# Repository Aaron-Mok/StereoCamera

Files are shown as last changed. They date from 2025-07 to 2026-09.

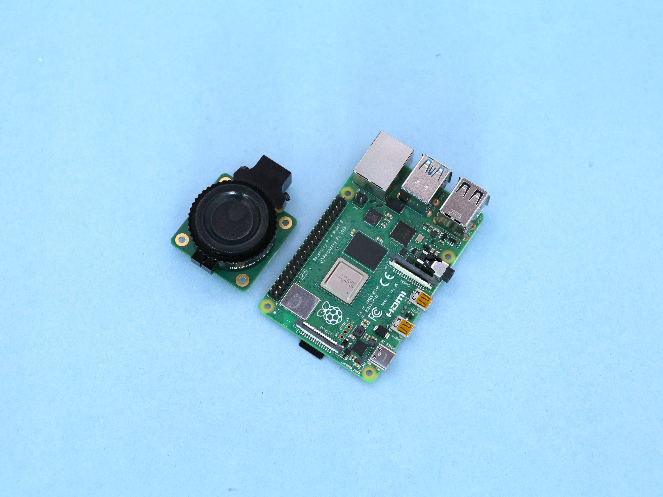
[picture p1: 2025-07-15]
CAD/Raspberry Pi HQ Camera Case - 4420496/images/parts-crop.jpg

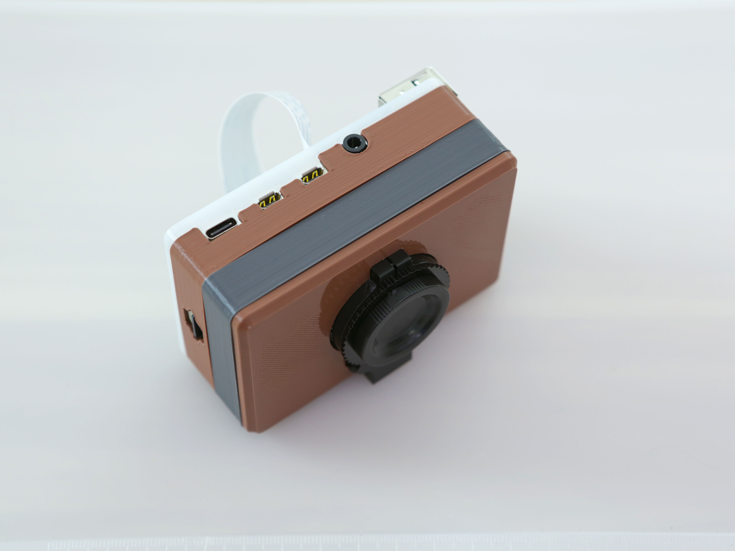
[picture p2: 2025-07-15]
CAD/Raspberry Pi HQ Camera Case - 4420496/images/final-build-top.jpg

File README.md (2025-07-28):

# Stereo Camera System

**Author:** Aaron Mok  
**Keywords:** Optics, Stereo Vision, Raspberry Pi HQ Camera, Depth Estimation, ISP Pipeline, Distortion Correction, Python, OpenCV, 3D Printing, CADing

## Overview

This project aims to build a complete **stereo camera system from scratch** using two Raspberry Pi HQ cameras. The system captures synchronized raw Bayer images, processes them through a custom image signal processing (ISP) pipeline, and performs stereo calibration and depth estimation. It also includes the design and fabrication of a **custom 3D-printed mount** to ensure precise camera alignment.

This project showcases the complete stereo vision pipeline, from lens and sensor selection to camera alignment and image processing, with the goal of achieving accurate and reliable depth reconstruction.

## Features

- **Raw Image Capture** from dual Raspberry Pi HQ cameras  
- **Custom ISP Pipeline** including:
  - Stride/padding correction
  - Black level subtraction
  - Distortion correction
  - Lens shading correction
  - Demosaicing
  - White balance
  - Color calibration
  - Gamma correction
- **Stereo Calibration & Rectification**
- **Disparity & Depth Map Generation**
- **Custom 3D-Printed Mount** for accurate and stable stereo alignment
- Real-time visualization and debugging tools
- Modular and extensible Python codebase

## Current Progress
**Status:** Ongoing Project  
- [x] Image signal processing for raw capture
  - [x] Stride/padding correction
  - [x] Black level subtraction
  - [ ] Distortion correction
  - [x] Lens shading correction
  - [x] Demosaicing
  - [x] White balance
  - [x] Color calibration
  - [x] Gamma correction
- [ ] 3D-printed mount design and testing
- [ ] Initial stereo calibration
- [ ] Real-time disparity map viewer

## Demo
Coming soon: live video walkthrough, depth map overlay, and stereo reconstruction results.

## About Me
I am an Imaging System Architect at KLA, where I lead the development of advanced optical and imaging subsystems for high-precision inspection tools. I hold a PhD in Biomedical Engineering from Cornell University, where my research focused on developing next-generation optical imaging systems for deep-tissue brain imaging.

See my work and blog at [https://aaron-mok.github.io/](https://aaron-mok.github.io/).

## License
This project is licensed under the **GNU General Public License v3.0**.

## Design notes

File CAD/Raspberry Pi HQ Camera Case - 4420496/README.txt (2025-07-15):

Raspberry Pi HQ Camera Case by adafruit on Thingiverse: https://www.thingiverse.com/thing:4420496

Summary:
In this project we’re making a case for the Raspberry Pi HQ Camera. This 3D printed an enclosure that houses the Pi 4 and the HQ Camera module. It’s compatible with any C or CS-mount lenses so we can use a wide variety of interchangeable lenses.Learn Guidehttps://learn.adafruit.com/raspberry-pi-hq-camera-case/YouTubehttps://youtu.be/g107_ErFv9kFusion 360 Share Linkhttps://a360.co/36TT8MJ3D Model – Raspberry Pi 4https://grabcad.com/library/raspberry-pi-4-model-b-13D Model – Pi HQ Camerahttps://grabcad.com/library/raspberry-pi-hq-camera-2Raspberry Pi 4https://www.adafruit.com/product/4296Raspberry Pi HQ Camerahttps://www.adafruit.com/product/45615.1 3A Power Supplyhttps://www.adafruit.com/product/4298M2.5 black nylon hardwarehttps://www.adafruit.com/product/329935mm 1.6f C-mount lenshttps://www.amazon.com/gp/product/B0773K3MXD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 HDMI cablehttps://www.adafruit.com/product/1322

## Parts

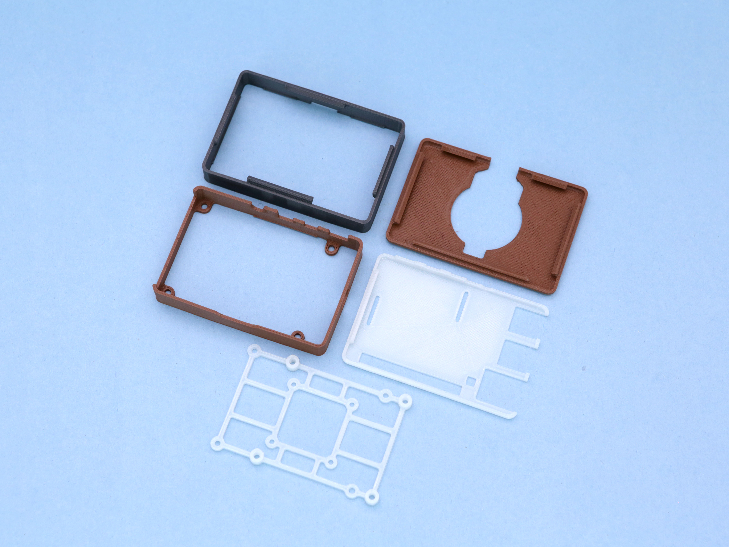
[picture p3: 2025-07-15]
CAD/Raspberry Pi HQ Camera Case - 4420496/images/3d-parts-crop.jpg

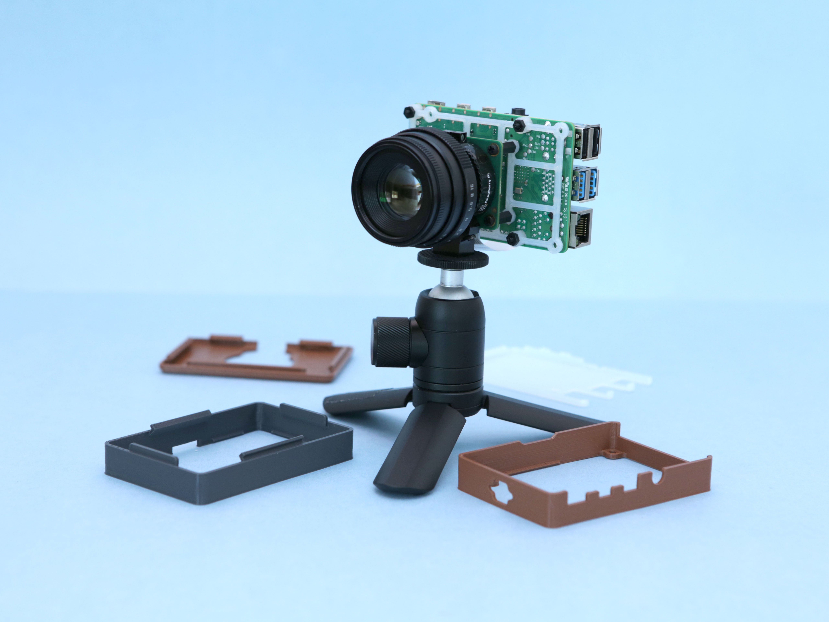
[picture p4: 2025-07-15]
CAD/Raspberry Pi HQ Camera Case - 4420496/images/pcb-mount-parts.jpg

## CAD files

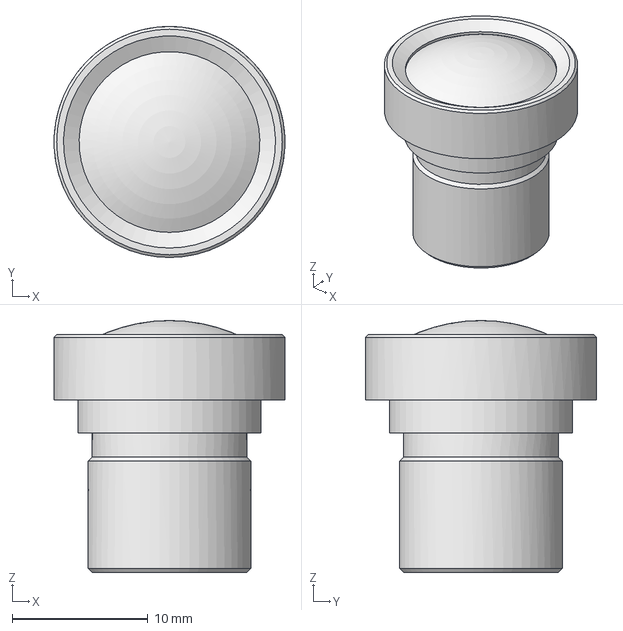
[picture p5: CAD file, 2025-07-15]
CAD/CIL034-F2.7-M12A660 v3/CIL034-F2.7-M12A660 v3.stp
17.0 x 17.0 x 18.5 mm

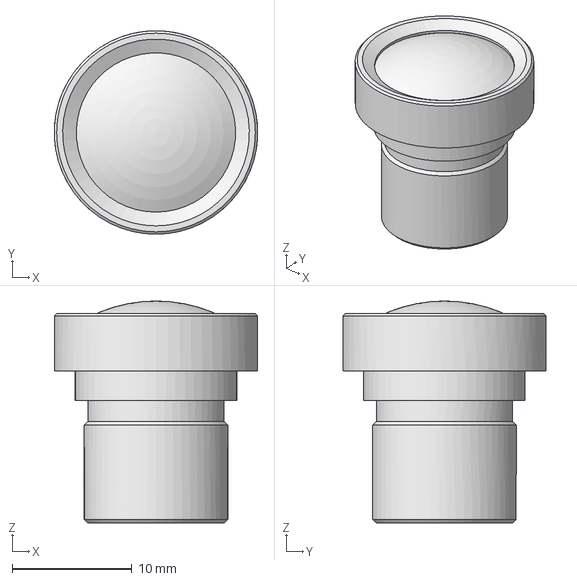
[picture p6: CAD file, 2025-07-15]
CAD/CIL034-F2.7-M12ANIR v3/CIL034-F2.7-M12ANIR v3.stp
17.0 x 17.0 x 18.5 mm

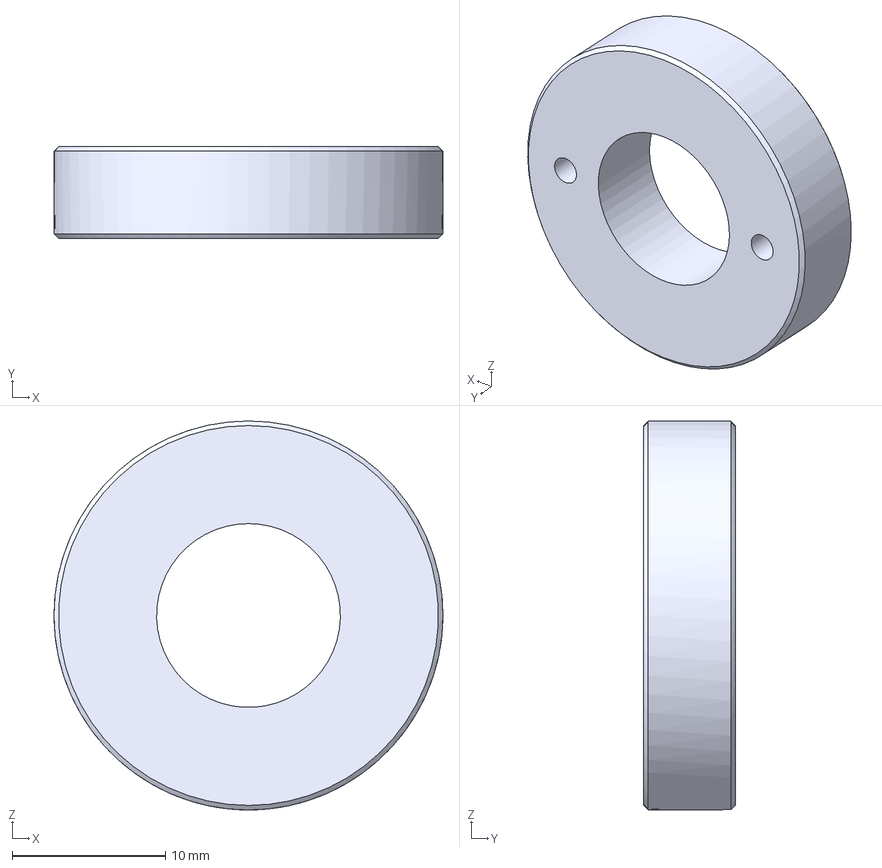
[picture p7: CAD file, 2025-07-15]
CAD/CLA-M12-C-Adapter.stp
25.4 x 6.00 x 25.4 mm

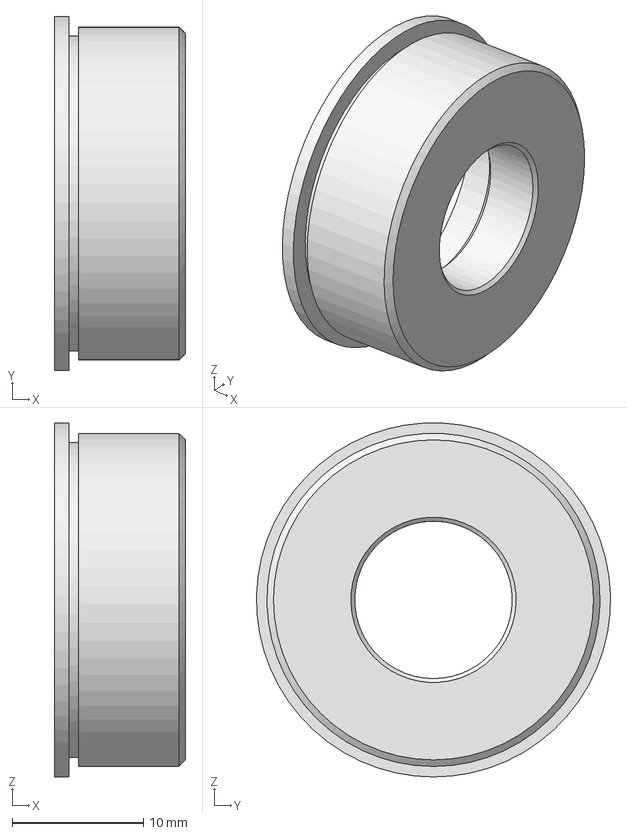
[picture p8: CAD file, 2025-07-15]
CAD/CLA125-CCS/CLA125-CCS.stp
10.00 x 27.0 x 27.0 mm

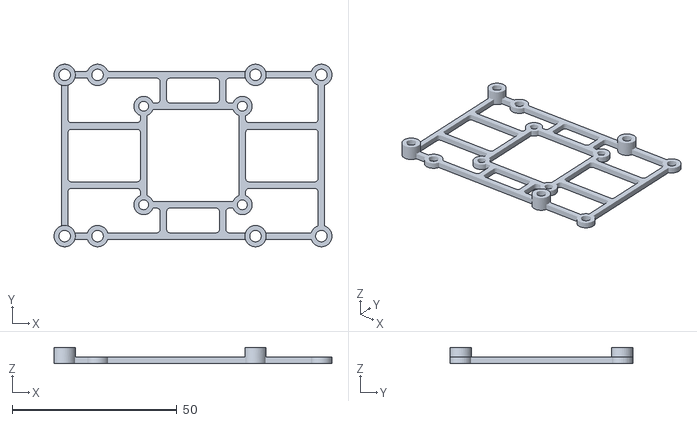
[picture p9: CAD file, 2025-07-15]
CAD/Raspberry Pi HQ Camera Case - 4420496/files/pcb-mount.stl
84.5 x 55.5 x 5.00

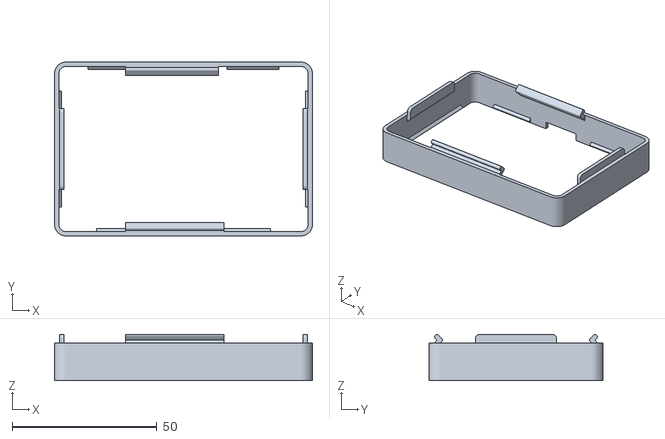
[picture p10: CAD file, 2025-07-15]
CAD/Raspberry Pi HQ Camera Case - 4420496/files/front-frame.stl
89.0 x 60.0 x 16.0

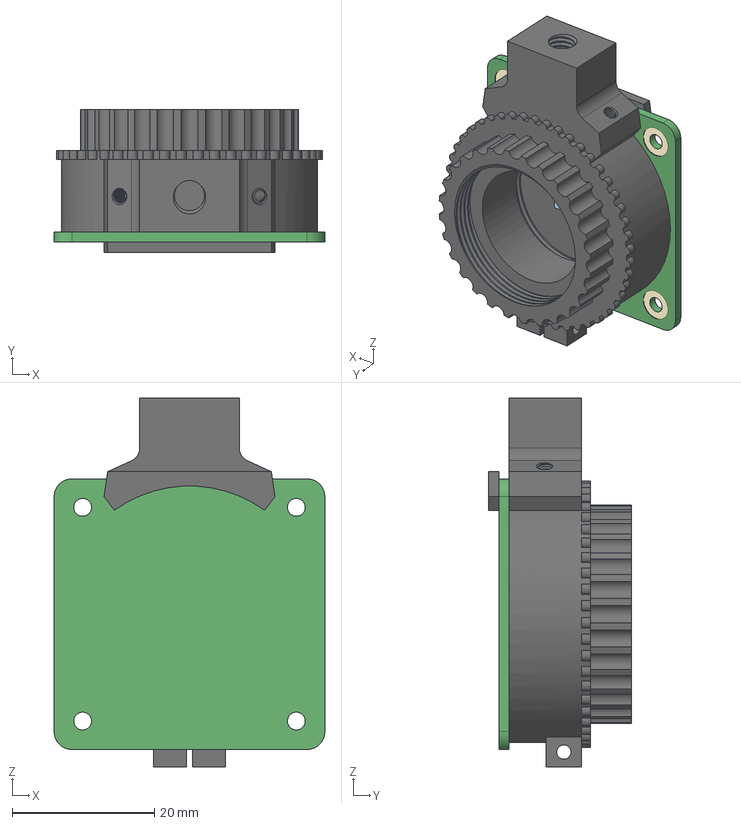
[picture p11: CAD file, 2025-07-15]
CAD/Raspberry Pi HQ Camera.step
38.0 x 20.1 x 51.8 mm

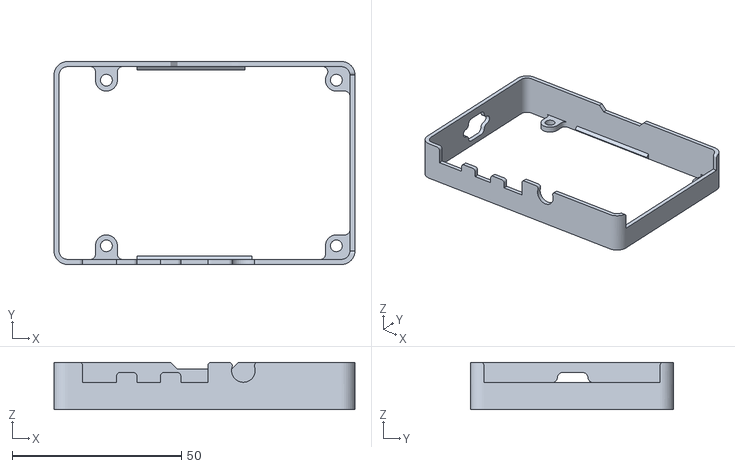
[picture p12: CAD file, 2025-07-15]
CAD/Raspberry Pi HQ Camera Case - 4420496/files/back-frame.stl
89.0 x 60.0 x 14.0

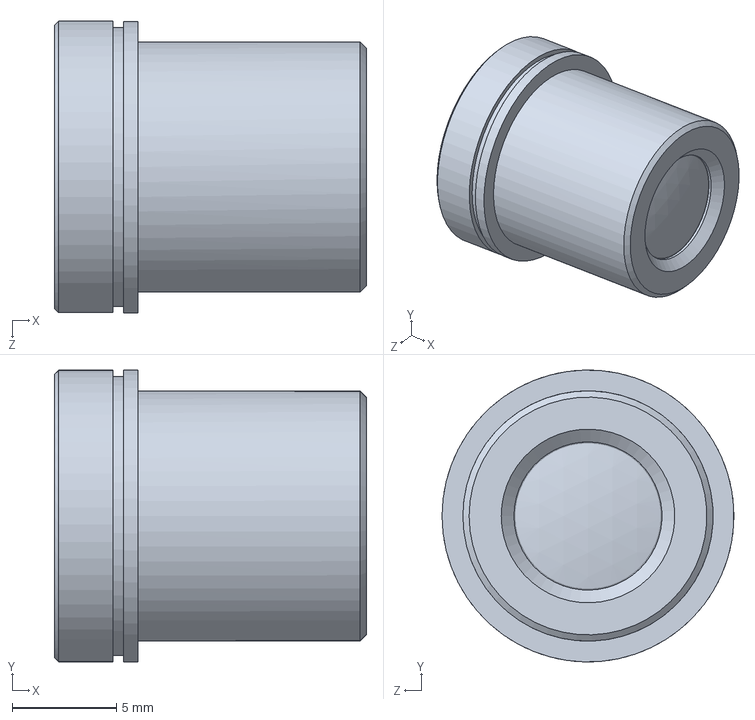
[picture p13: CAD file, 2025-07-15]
CAD/step_69255.step
15.0 x 14.0 x 14.0 mm

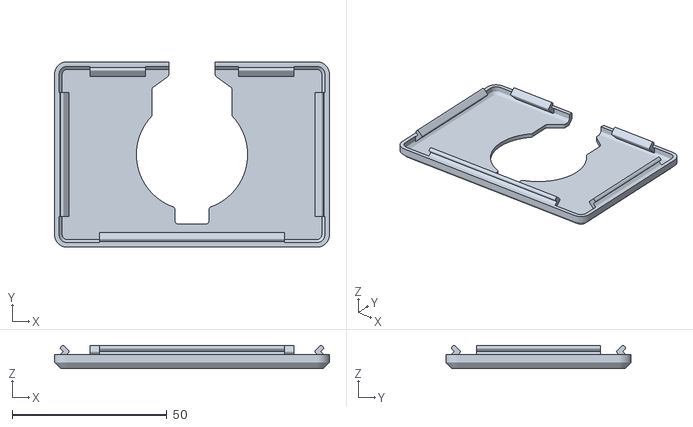
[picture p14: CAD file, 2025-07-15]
CAD/Raspberry Pi HQ Camera Case - 4420496/files/front-cover.stl
89.0 x 60.0 x 7.49

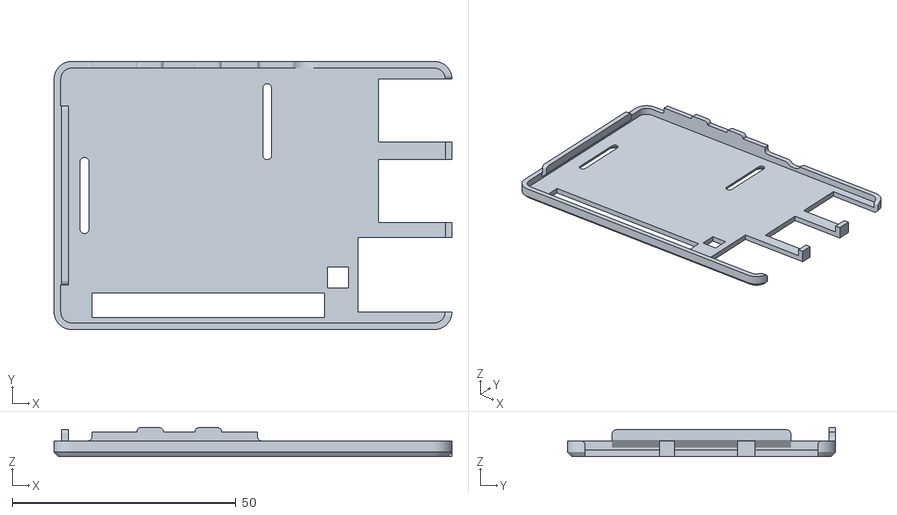
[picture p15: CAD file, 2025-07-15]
CAD/Raspberry Pi HQ Camera Case - 4420496/files/back-cover.stl
89.0 x 60.0 x 6.50

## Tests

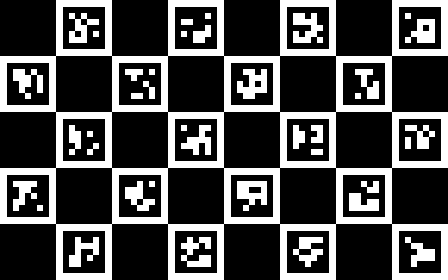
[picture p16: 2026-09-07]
Calibration_output/charuco_8x5_100mm_preview.png

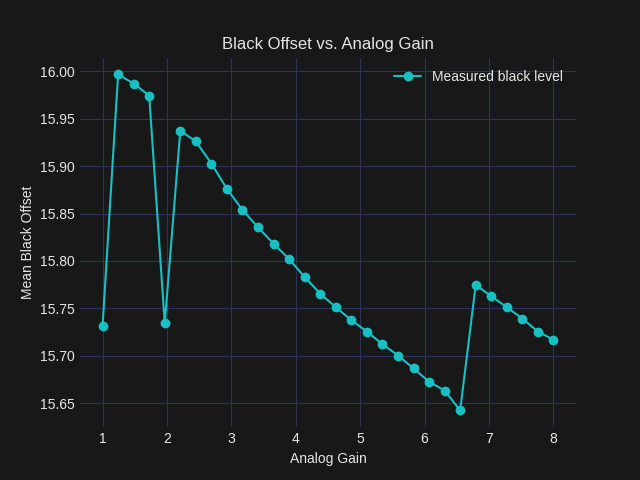
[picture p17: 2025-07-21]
Calibration_output/black_offset.png

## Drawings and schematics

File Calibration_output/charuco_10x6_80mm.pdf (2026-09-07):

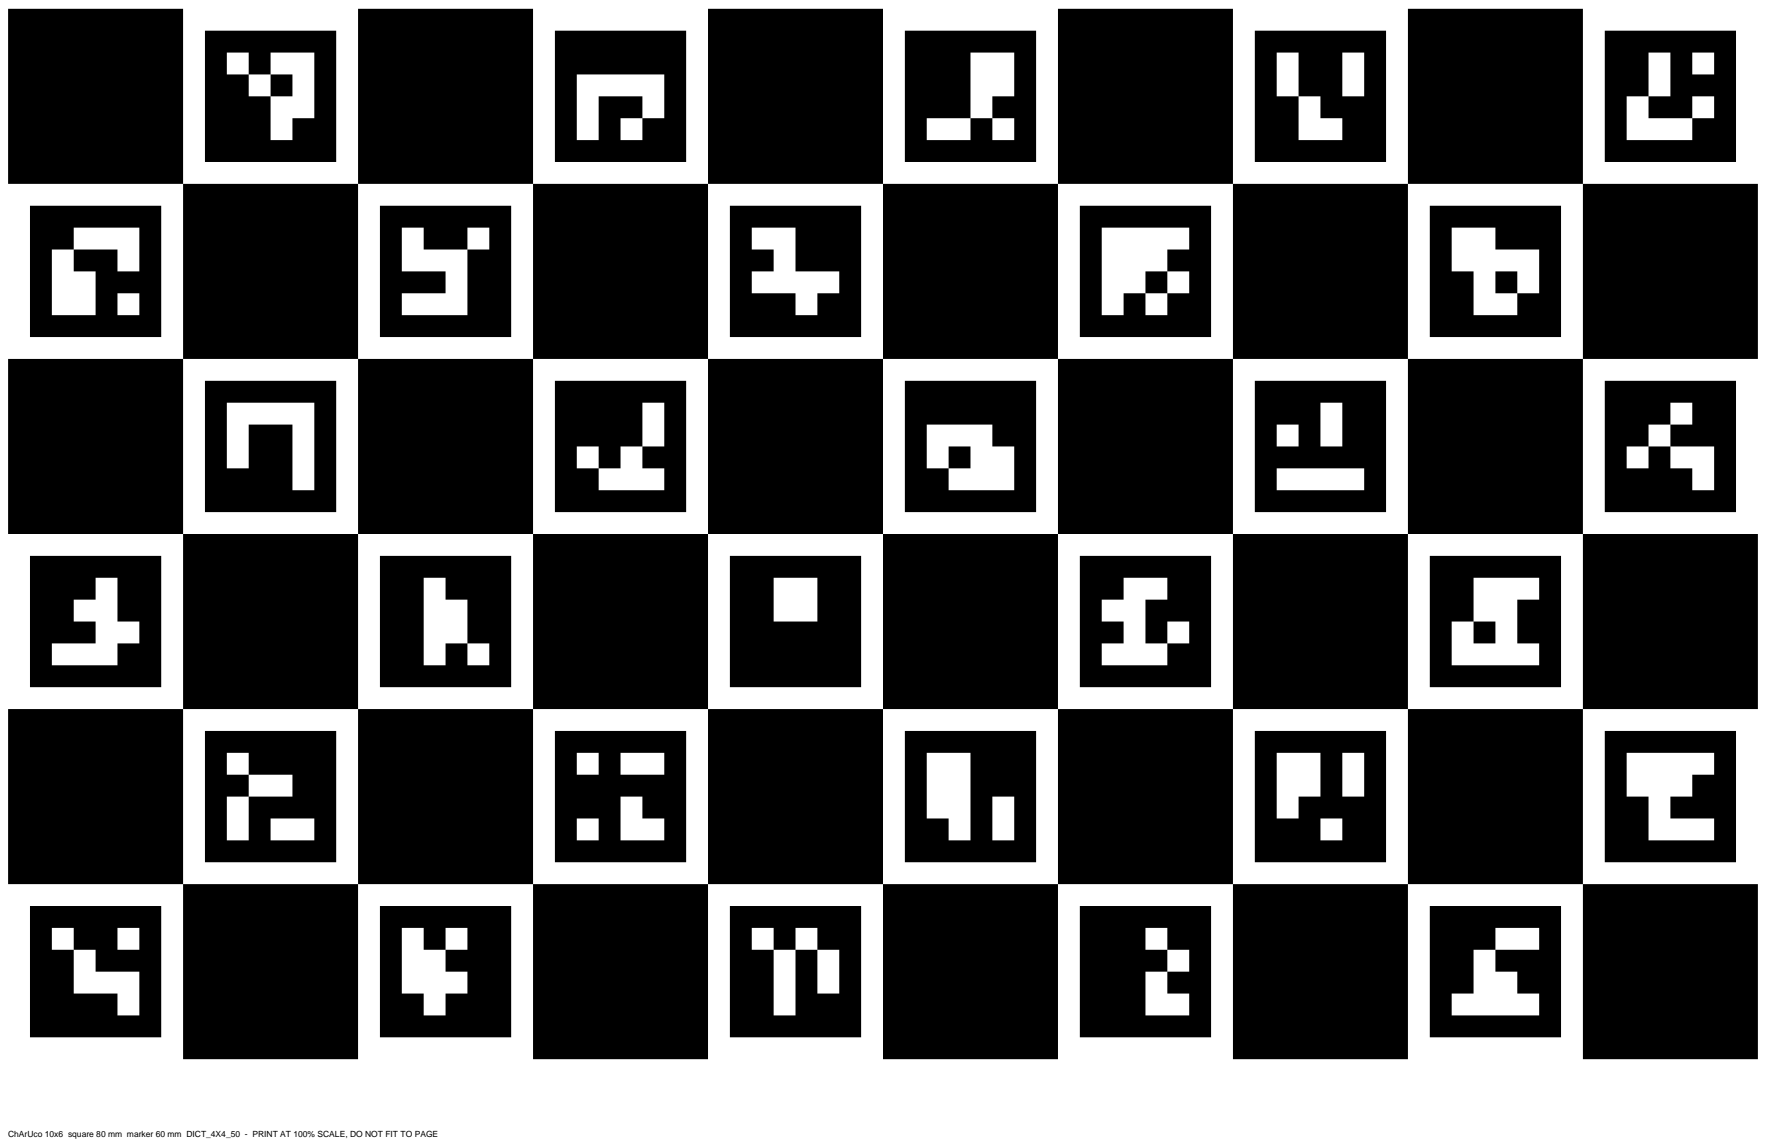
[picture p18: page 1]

ChArUco 10x6 square 80 mm marker 60 mm DICT_4X4_50 - PRINT AT 100% SCALE, DO NOT FIT TO PAGE

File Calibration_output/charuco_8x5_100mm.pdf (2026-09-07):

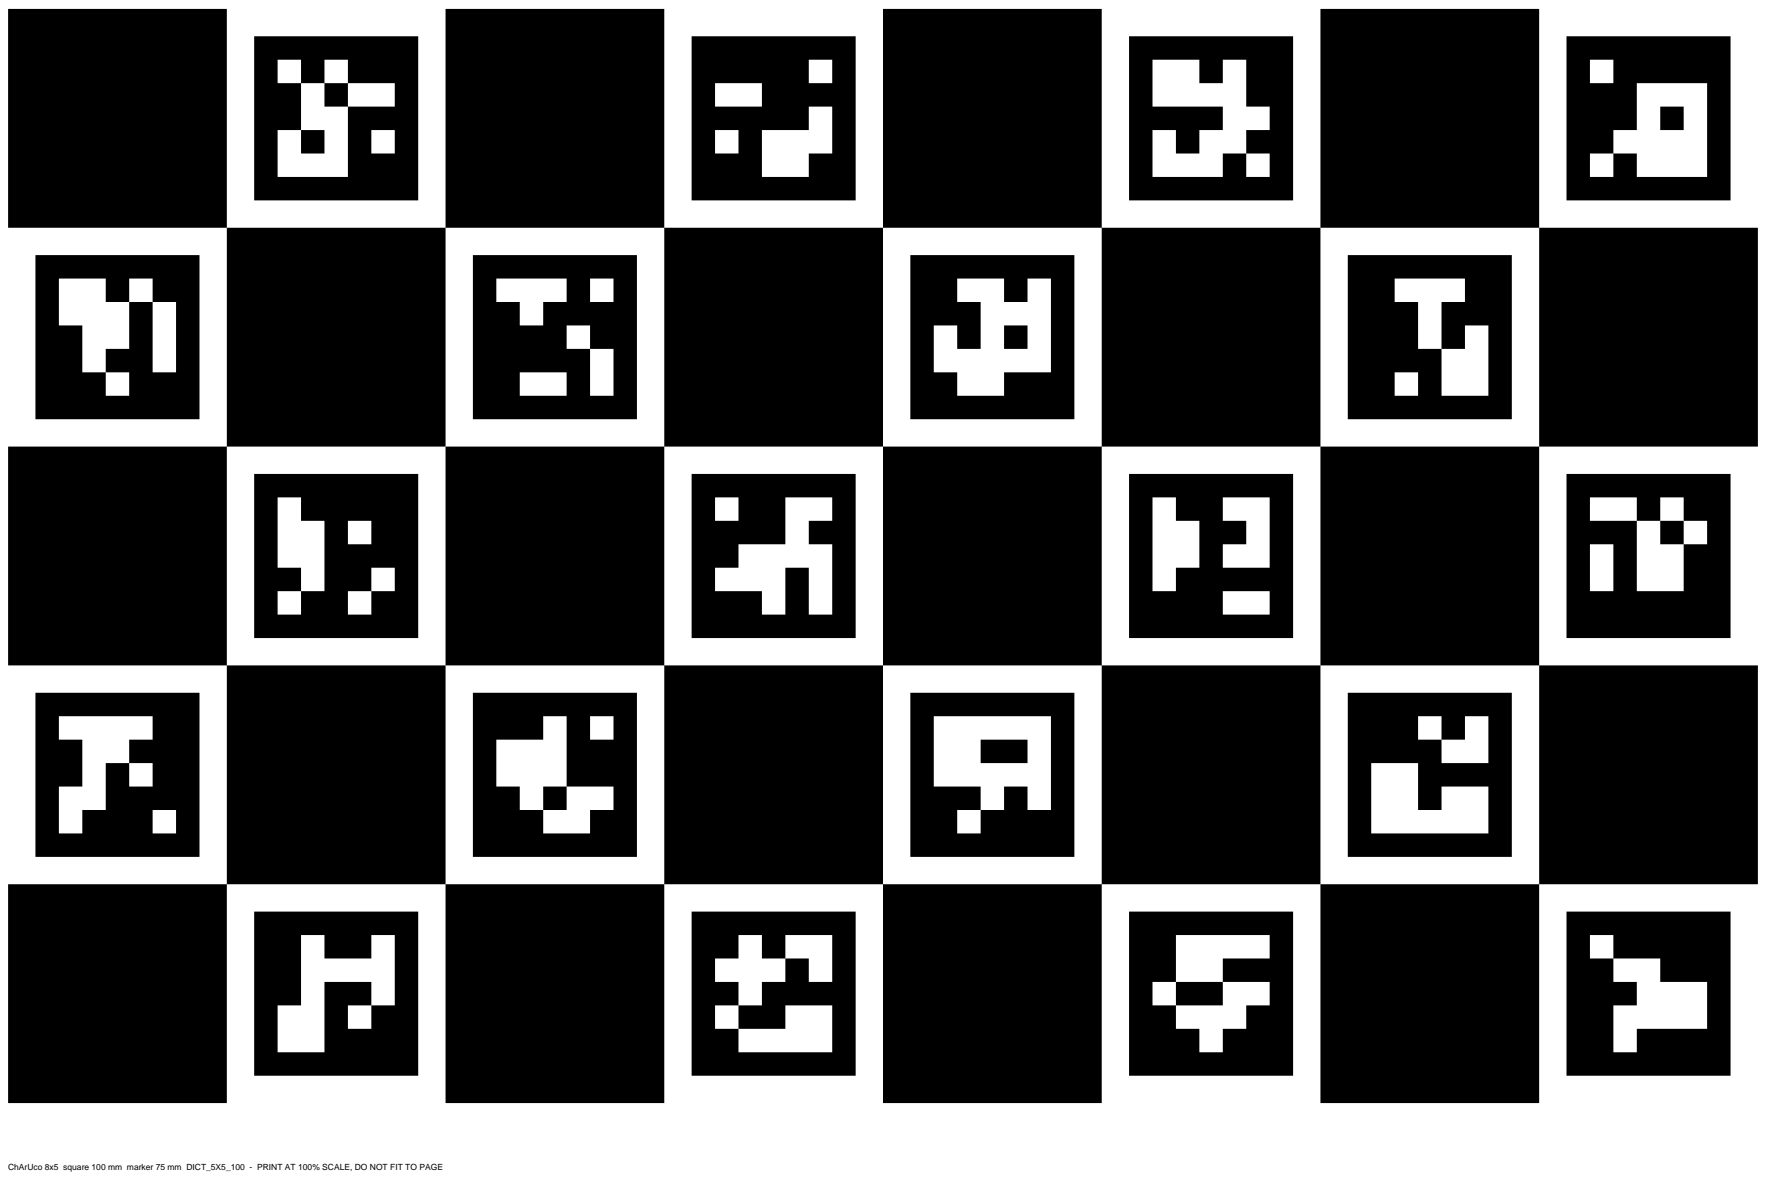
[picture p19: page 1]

ChArUco 8x5 square 100 mm marker 75 mm DICT_5X5_100 - PRINT AT 100% SCALE, DO NOT FIT TO PAGE

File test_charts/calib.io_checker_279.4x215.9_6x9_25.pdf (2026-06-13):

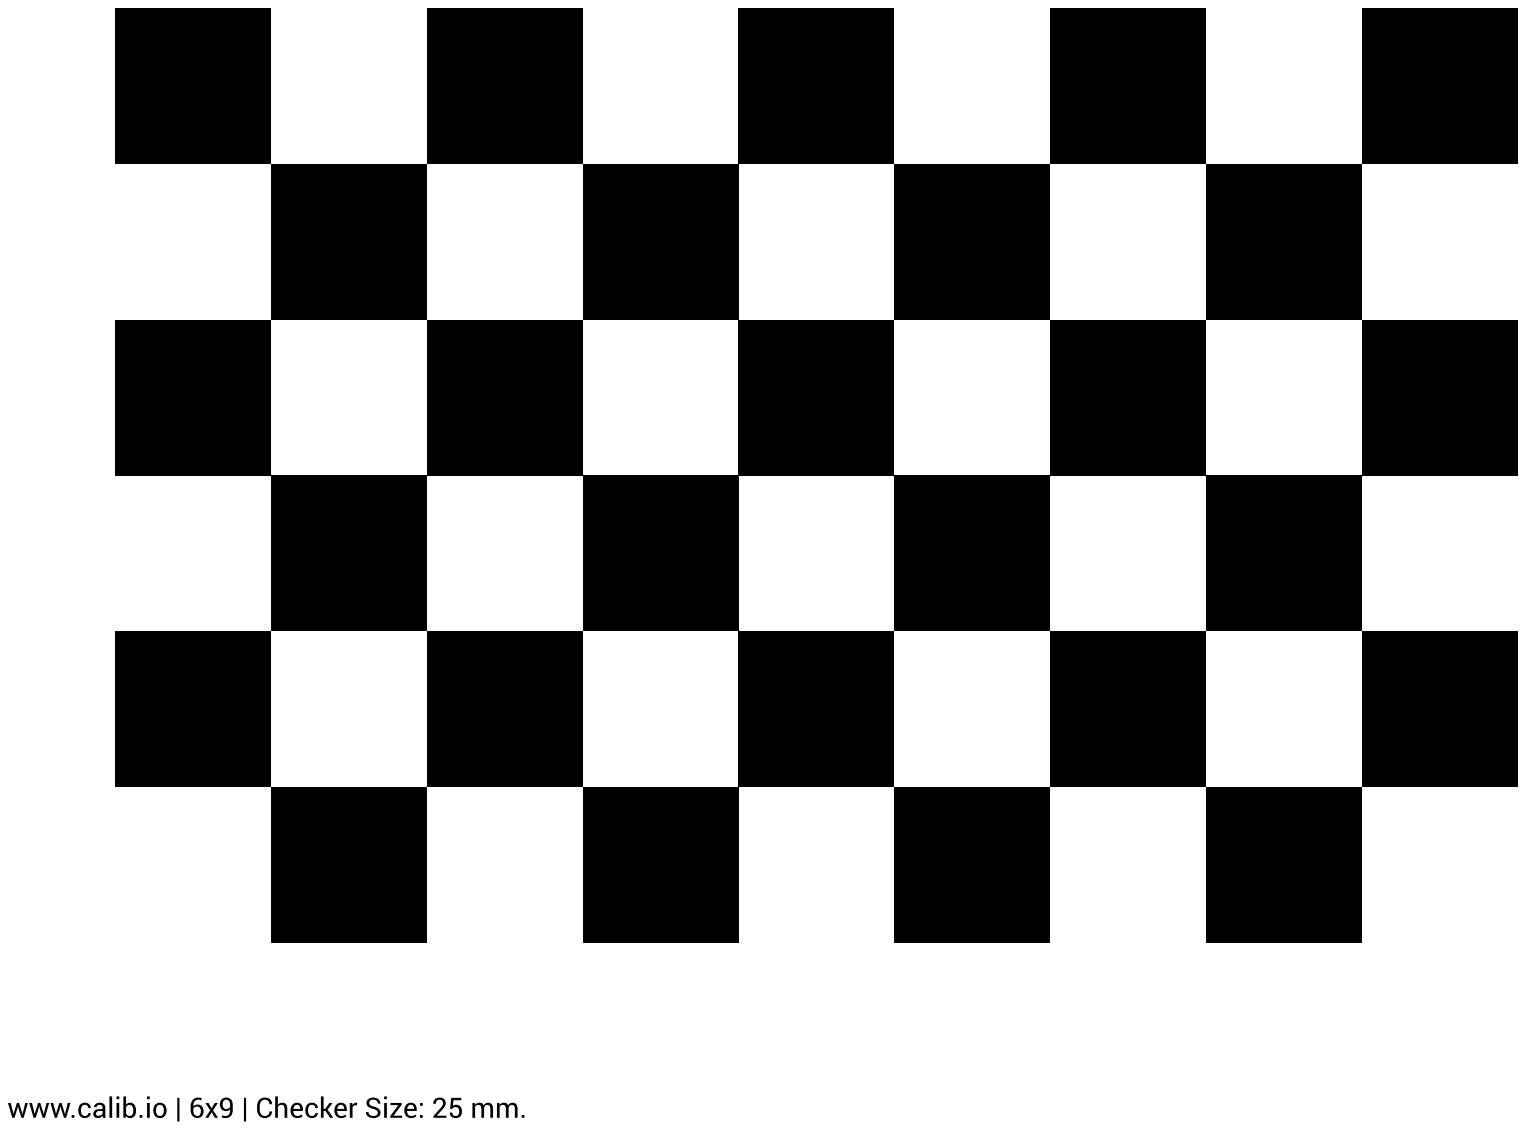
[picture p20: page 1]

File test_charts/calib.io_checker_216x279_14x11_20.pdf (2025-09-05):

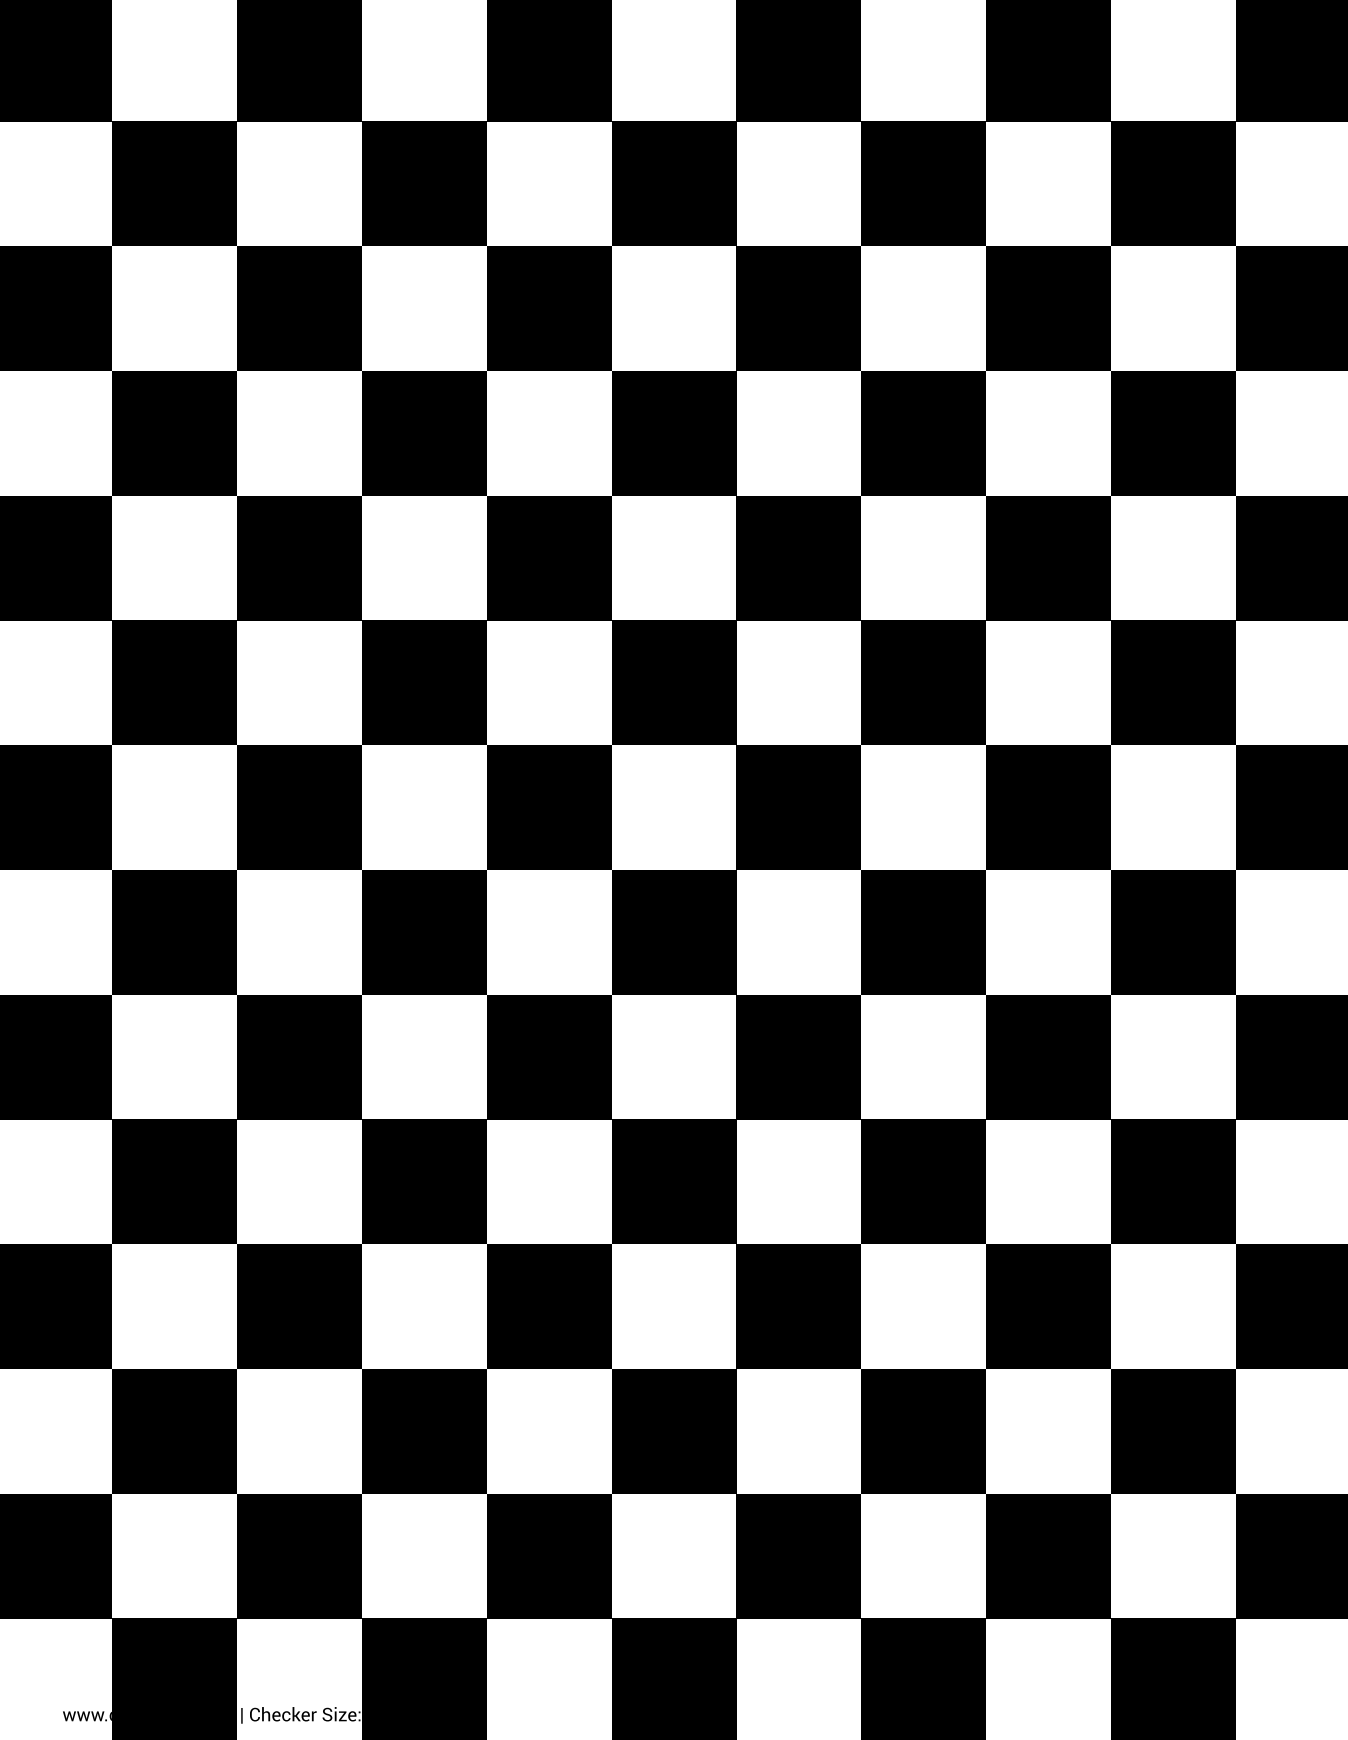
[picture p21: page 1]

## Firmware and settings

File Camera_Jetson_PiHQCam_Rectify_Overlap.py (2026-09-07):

import sys
import os
sys.path.insert(0, os.path.abspath(os.path.join(os.path.dirname(__file__), "..")))

import time
import numpy as np
import cv2
from ISP.binning import extract_green
from camera_utils import initialize_camera_jetson, capture_raw_frame_jetson
from conversion_utils import bit16_to_bit8

# ─── Settings ──────────────────────────────────────────────────────────────────
LEFT_DEVICE  = "/dev/video0"
RIGHT_DEVICE = "/dev/video1"

W, H       = 3840, 2160
EXPOSURE   = 33000
GAIN       = 200
FRAME_RATE = 30000000

CALIB_FILE  = "Calibration_output/20260620_stereo_params.yml"
CAPTURE_DIR = "captures"

DISP_W, DISP_H = 960, 540   # display size of the overlap view
FLICKER_FRAMES = 8          # frames per side in flicker mode
MEASURE_EVERY  = 30         # run the alignment measurement every N frames (~56 ms each)
ORB_FEATURES   = 800        # features per view for the measurement
MIN_MATCHES    = 20         # below this the measurement is reported as unavailable
DY_SPAN_PX     = 100        # display px; row errors are only searched within +-this
DY_BIN_PX      = 2          # vote bin width when looking for the dominant row error
DY_INLIER_PX   = 3          # display px around the winning bin that counts as an inlier

# Disparity matcher — same settings as Camera_Jetson_PiHQCam_Stereo.py
NUM_DISPARITIES  = 16 * 16  # must be multiple of 16; CUDA StereoBM max is 256
BLOCK_SIZE       = 5        # must be odd; 5-21 for StereoBM
TEXTURE_THRESH   = 20       # mask pixels with too little texture
UNIQUENESS_RATIO = 20       # reject match if 2nd-best is within this % of best (0=off)
PREFILTER_CAP    = 31       # clamp prefilter response; 1-63

# The calibration solves /dev/video0 as camera 1, but the recovered geometry puts
# camera 1 to the *right* of camera 2 (P2[0,3] > 0, T_x > 0, and rectified
# chessboard corners give xL - xR < 0) — the cameras are rolled 180 deg, same
# reason the preview needs ROTATE_180. Swap the eyes after rectification so the
# overlay is a true left/right pair. Set False if you recalibrate in device order.
SWAP_EYES = True
# ───────────────────────────────────────────────────────────────────────────────

MODES = {
    ord('1'): "anaglyph",     # left = red, right = cyan
    ord('2'): "blend",        # 50/50 average
    ord('3'): "difference",   # |L - R|, gain x2
    ord('4'): "flicker",      # alternate L/R in place
    ord('5'): "side-by-side", # the classic rectified pair
}


def raw_to_gray8(raw_u16):
    """Raw 4K Bayer → 1920×1080 uint8 green channel (matches calibration resolution)."""
    return bit16_to_bit8(extract_green(raw_u16))


def load_calibration(path):
    fs = cv2.FileStorage(path, cv2.FILE_STORAGE_READ)
    map1x = fs.getNode("map1x").mat()
    map1y = fs.getNode("map1y").mat()
    map2x = fs.getNode("map2x").mat()
    map2y = fs.getNode("map2y").mat()
    Q     = fs.getNode("Q").mat()
    P2    = fs.getNode("P2").mat()
    fs.release()
    focal    = Q[2, 3]             # focal length in pixels (from rectified projection)
    baseline = 1.0 / abs(Q[3, 2])  # baseline in metres
    return map1x, map1y, map2x, map2y, Q, P2, focal, baseline


def valid_mask(mapx, mapy, src_w, src_h):
    """True where a rectified pixel actually samples inside the source image."""
    return ((mapx >= 0) & (mapx <= src_w - 1) &
            (mapy >= 0) & (mapy <= src_h - 1))


def shift_x(img, dx):
    """Shift horizontally by dx px, filling the vacated edge with black."""
    if dx == 0:
        return img
    out = np.zeros_like(img)
    if dx > 0:
        out[:, dx:] = img[:, :-dx]
    else:
        out[:, :dx] = img[:, -dx:]
    return out


def disparity_warp(right, disp_disp_px, grid_x, grid_y):
    """Pull the right view onto the left one using a per-pixel x offset.

    StereoBM gives disparity in the *left* frame, so the pixel matching left
    (x, y) sits at (x - d, y) in the right view — sampling there lands every
    depth on top of its match at once, where the manual [/] shift can only ever
    align one plane. Pixels with no disparity keep d = 0 and stay misaligned;
    they are dimmed by the caller rather than hidden, so a bad match looks bad.
    """
    return cv2.remap(right, grid_x - disp_disp_px, grid_y, cv2.INTER_LINEAR,
                     borderMode=cv2.BORDER_CONSTANT, borderValue=0)


def compose(left, right, mode, frame_idx):
    """Combine the two rectified views into one BGR image."""
    if mode == "anaglyph":
        return np.dstack([right, right, left])          # L→red, R→cyan
    if mode == "blend":
        return cv2.cvtColor(cv2.addWeighted(left, 0.5, right, 0.5, 0), cv2.COLOR_GRAY2BGR)
    if mode == "difference":
        diff = cv2.convertScaleAbs(cv2.absdiff(left, right), alpha=2.0)
        return cv2.cvtColor(diff, cv2.COLOR_GRAY2BGR)
    if mode == "flicker":
        side = left if (frame_idx // FLICKER_FRAMES) % 2 == 0 else right
        return cv2.cvtColor(side, cv2.COLOR_GRAY2BGR)
    # side-by-side
    return cv2.cvtColor(np.hstack([left, right]), cv2.COLOR_GRAY2BGR)


ORB = cv2.ORB_create(ORB_FEATURES)
BF  = cv2.BFMatcher(cv2.NORM_HAMMING, crossCheck=True)


def estimate_alignment(left, right):
    """Median row error and disparity from ORB matches, in *display* px.

    dy near 0 means the pair really is rectified; disparity must be positive —
    a negative value means the two eyes are the wrong way round. Phase
    correlation was tried here first and is not usable: on a scene with mixed
    depths it locks onto whichever plane dominates and reports nonsense dy at
    low confidence. Returns None when there are too few matches to trust.
    """
    kpL, desL = ORB.detectAndCompute(left, None)
    kpR, desR = ORB.detectAndCompute(right, None)
    if desL is None or desR is None:
        return None

    matches = BF.match(desL, desR)
    if len(matches) < MIN_MATCHES:
        return None

    ptsL = np.float32([kpL[m.queryIdx].pt for m in matches])
    ptsR = np.float32([kpR[m.trainIdx].pt for m in matches])
    dy   = ptsR[:, 1] - ptsL[:, 1]
    dx   = ptsL[:, 0] - ptsR[:, 0]   # disparity: positive for a correctly ordered pair

    # Vote for the dominant row error rather than taking a median: on repetitive
    # texture most matches are wrong, and a median of mostly-wrong matches is a
    # confident wrong answer. A vote lets the correct matches win, or fail loudly.
    in_range = np.abs(dy) < DY_SPAN_PX
    if in_range.sum() < MIN_MATCHES:
        return None
    votes, edges = np.histogram(dy[in_range], bins=int(2 * DY_SPAN_PX / DY_BIN_PX),
                                range=(-DY_SPAN_PX, DY_SPAN_PX))
    peak = edges[votes.argmax()] + DY_BIN_PX / 2

    inliers = np.abs(dy - peak) < DY_INLIER_PX
    if inliers.sum() < MIN_MATCHES:
        return None
    return np.median(dy[inliers]), np.median(dx[inliers]), int(inliers.sum())


def alignment_text(alignment, scale):
    """One-line summary of an estimate_alignment() result, in rectified px."""
    if alignment is None:
        return "row error: too few matches"
    dy, disparity, n = alignment
    return (f"row error dy={dy * scale:+.2f} px   "
            f"disparity={disparity * scale:+.1f} px   n={n}")


def draw_hud(view, lines):
    for i, text in enumerate(lines):
        cv2.putText(view, text, (10, 22 + i * 22), cv2.FONT_HERSHEY_SIMPLEX,
                    0.55, (0, 200, 255), 1, cv2.LINE_AA)
    return view


os.makedirs(CAPTURE_DIR, exist_ok=True)

print(f"[i] Loading calibration from '{CALIB_FILE}' ...")
map1x, map1y, map2x, map2y, Q, P2, FOCAL_PX, BASELINE_M = load_calibration(CALIB_FILE)
print(f"[i] focal={FOCAL_PX:.1f} px  baseline={BASELINE_M*100:.1f} cm")

# OpenCV writes P2[0,3] = -fx * baseline, so a positive value means camera 1
# (LEFT_DEVICE) is the right-eye view and the pair has to be swapped.
calib_swapped = P2[0, 3] > 0
if calib_swapped != SWAP_EYES:
    print(f"[!] SWAP_EYES={SWAP_EYES} but P2[0,3]={P2[0,3]:+.1f} says the eyes are "
          f"{'swapped' if calib_swapped else 'in device order'} — disparity will come out negative.")
print(f"[i] left eye = {RIGHT_DEVICE if SWAP_EYES else LEFT_DEVICE}, "
      f"right eye = {LEFT_DEVICE if SWAP_EYES else RIGHT_DEVICE}")

RECT_H, RECT_W = map1x.shape[:2]
SRC_W, SRC_H   = W // 2, H // 2   # extract_green halves both dimensions
SCALE          = RECT_W / DISP_W  # display px → rectified px

# Overlap = pixels that are valid in *both* rectified views
maskL   = valid_mask(map1x, map1y, SRC_W, SRC_H)
maskR   = valid_mask(map2x, map2y, SRC_W, SRC_H)
common  = (maskL & maskR)
ys, xs  = np.where(common)
if ys.size == 0:
    raise RuntimeError("Rectified views do not overlap — check the calibration file.")
OVERLAP_BOX = (xs.min(), ys.min(), xs.max(), ys.max())
overlap_pct = 100.0 * common.sum() / common.size
print(f"[i] rectified size {RECT_W}x{RECT_H} — common FOV {overlap_pct:.1f}% of frame, "
      f"bbox x[{OVERLAP_BOX[0]}..{OVERLAP_BOX[2]}] y[{OVERLAP_BOX[1]}..{OVERLAP_BOX[3]}]")

common_small = cv2.resize(common.astype(np.uint8) * 255, (DISP_W, DISP_H),
                          interpolation=cv2.INTER_NEAREST)
inside_small  = common_small > 0                              # unrotated, for valid-% stats
outside_small = cv2.rotate(common_small, cv2.ROTATE_180) == 0  # preview is rotated 180

# Sampling grid for the disparity warp, in display coordinates
GRID_X, GRID_Y = np.meshgrid(np.arange(DISP_W, dtype=np.float32),
                             np.arange(DISP_H, dtype=np.float32))

# Upload rectification maps to GPU once at startup
gpu_map1x = cv2.cuda_GpuMat(); gpu_map1x.upload(map1x)
gpu_map1y = cv2.cuda_GpuMat(); gpu_map1y.upload(map1y)
gpu_map2x = cv2.cuda_GpuMat(); gpu_map2x.upload(map2x)
gpu_map2y = cv2.cuda_GpuMat(); gpu_map2y.upload(map2y)

# CUDA StereoBM — same matcher as the depth script, on the rectified pair
try:
    matcher = cv2.cuda.createStereoBM(numDisparities=NUM_DISPARITIES, blockSize=BLOCK_SIZE)
    matcher.setPreFilterType(cv2.StereoBM_PREFILTER_XSOBEL)
    matcher.setPreFilterCap(PREFILTER_CAP)
    matcher.setTextureThreshold(TEXTURE_THRESH)
    matcher.setUniquenessRatio(UNIQUENESS_RATIO)
    stream = cv2.cuda.Stream()
except (cv2.error, AttributeError) as exc:
    matcher = None
    print(f"[!] CUDA StereoBM unavailable ({exc}) — disparity warp disabled.")

print("[i] Initialising cameras ...")
p0, _ = initialize_camera_jetson(LEFT_DEVICE,  W, H, EXPOSURE, GAIN, FRAME_RATE)
p1, _ = initialize_camera_jetson(RIGHT_DEVICE, W, H, EXPOSURE, GAIN, FRAME_RATE)

WIN_BEFORE = "Before rectification"
WIN_AFTER  = "After rectification"
WIN_WARP   = "After disparity warp"
cv2.namedWindow(WIN_BEFORE); cv2.moveWindow(WIN_BEFORE, 0, 0)
cv2.namedWindow(WIN_AFTER);  cv2.moveWindow(WIN_AFTER, DISP_W + 10, 0)
cv2.namedWindow(WIN_WARP);   cv2.moveWindow(WIN_WARP, DISP_W + 10, DISP_H + 40)

print("[i] Running — 1-5 view mode, m=mask non-overlap, [/]=shift right view, "
      "0=reset shift, d=disparity warp, a=snap shift to median disparity, c=capture, q=quit.")

mode          = "anaglyph"
show_mask     = True
shift_disp    = 0      # horizontal shift of the right view, in display px
frame_idx     = 0
capture_count = 1
align_before  = None
align_after   = None
align_warp    = None
show_warp     = matcher is not None
warp          = np.zeros((DISP_H, DISP_W, 3), np.uint8)
med_disp_rect = None   # median valid disparity, in rectified px
valid_pct     = 0.0

while True:
    raw_0 = capture_raw_frame_jetson(p0, W, H)
    raw_1 = capture_raw_frame_jetson(p1, W, H)
    if raw_0 is None or raw_1 is None:
        print("[!] Frame grab failed.")
        break

    gray0 = raw_to_gray8(raw_0)
    gray1 = raw_to_gray8(raw_1)

    # Upload to GPU and remap — map1* belongs to video0, map2* to video1
    gpu_gray0 = cv2.cuda_GpuMat(); gpu_gray0.upload(gray0)
    gpu_gray1 = cv2.cuda_GpuMat(); gpu_gray1.upload(gray1)

    gpu_rect0 = cv2.cuda.remap(gpu_gray0, gpu_map1x, gpu_map1y, cv2.INTER_LINEAR)
    gpu_rect1 = cv2.cuda.remap(gpu_gray1, gpu_map2x, gpu_map2y, cv2.INTER_LINEAR)

    # Assign eyes only after rectification; the maps stay bound to their device
    gpu_rectL, gpu_rectR = (gpu_rect1, gpu_rect0) if SWAP_EYES else (gpu_rect0, gpu_rect1)

    # Downscale on GPU; measure and shift in rectified coordinates ...
    rawL_small,  rawR_small  = [cv2.cuda.resize(g, (DISP_W, DISP_H)).download()
                                for g in ((gpu_gray1, gpu_gray0) if SWAP_EYES else
                                          (gpu_gray0, gpu_gray1))]
    rectL_small, rectR_small = [cv2.cuda.resize(g, (DISP_W, DISP_H)).download()
                                for g in (gpu_rectL, gpu_rectR)]

    # ── Dense disparity → per-pixel x offset → right view pulled onto the left ──
    warpR_small = None
    if show_warp:
        # Matched in rectified orientation, where the epipolar lines are rows;
        # rotating first would flip the sign of every disparity.
        gpu_disp = matcher.compute(gpu_rectL, gpu_rectR, stream)
        stream.waitForCompletion()
        disp_small = cv2.cuda.resize(gpu_disp, (DISP_W, DISP_H),
                                     interpolation=cv2.INTER_NEAREST).download()

        # CUDA StereoBM returns whole-pixel CV_8U disparity (no 1/16 fixed point),
        # in rectified px — rescale to display px before warping the small view.
        disp_valid = disp_small > 0
        warpR_small = disparity_warp(rectR_small, disp_small.astype(np.float32) / SCALE,
                                     GRID_X, GRID_Y)

        matched   = disp_valid & inside_small
        valid_pct = 100.0 * matched.sum() / max(inside_small.sum(), 1)
        med_disp_rect = float(np.median(disp_small[disp_valid])) if disp_valid.any() else None
        no_disp_small = cv2.rotate((~disp_valid).astype(np.uint8), cv2.ROTATE_180) > 0

    # One measurement per frame, staggered — running both costs ~110 ms and stutters
    if frame_idx % MEASURE_EVERY == 0:
        align_after = estimate_alignment(rectL_small, rectR_small)
    elif frame_idx % MEASURE_EVERY == 1:
        align_before = estimate_alignment(rawL_small, rawR_small)
    elif frame_idx % MEASURE_EVERY == 2 and warpR_small is not None:
        # Residual after the warp: dx should collapse to ~0 where the match is good
        align_warp = estimate_alignment(rectL_small, warpR_small)

    # ... then rotate into viewing orientation (the cameras are mounted upside down)
    before = compose(cv2.rotate(rawL_small, cv2.ROTATE_180),
                     cv2.rotate(rawR_small, cv2.ROTATE_180), mode, frame_idx)
    after  = compose(cv2.rotate(rectL_small, cv2.ROTATE_180),
                     cv2.rotate(shift_x(rectR_small, shift_disp), cv2.ROTATE_180),
                     mode, frame_idx)

    if warpR_small is not None:
        warp = compose(cv2.rotate(rectL_small, cv2.ROTATE_180),
                       cv2.rotate(warpR_small, cv2.ROTATE_180), mode, frame_idx)

    # Dim whatever falls outside the common field of view (rectified view only)
    if show_mask and mode != "side-by-side":
        after[outside_small] = (after[outside_small] * 0.35).astype(np.uint8)
        after[outside_small, 2] = np.clip(after[outside_small, 2] + 40, 0, 255)
        if warpR_small is not None:
            # Dim both the non-overlap and the pixels the matcher gave up on, so
            # what stays bright is exactly what the disparity actually aligned
            dim = outside_small | no_disp_small
            warp[dim] = (warp[dim] * 0.35).astype(np.uint8)
            warp[dim, 2] = np.clip(warp[dim, 2] + 40, 0, 255)

    # ── Readout: shift in rectified px, and the depth that shift aligns ──────
    shift_rect = shift_disp * SCALE
    depth_txt  = "-"
    if abs(shift_rect) > 0.5:
        depth_txt = f"{(FOCAL_PX * BASELINE_M) / abs(shift_rect):.2f} m"

    draw_hud(before, [
        f"BEFORE rectification (raw green, eyes assigned)  |  {mode}",
        alignment_text(align_before, SCALE),
    ])
    draw_hud(after, [
        f"AFTER rectification  |  overlap {overlap_pct:.1f}%  |  1-5 modes  m=mask  q=quit",
        f"shift {shift_rect:+.0f} px (aligns ~{depth_txt})   [ ] to adjust, 0 to reset",
        alignment_text(align_after, SCALE),
    ])

    if show_warp:
        med_txt = "-"
        if med_disp_rect:
            med_txt = (f"{med_disp_rect:.1f} px (~{(FOCAL_PX * BASELINE_M) / med_disp_rect:.2f} m)")
        draw_hud(warp, [
            f"AFTER disparity warp  |  right eye pulled onto left, per pixel",
            f"matched {valid_pct:.0f}% of overlap   median disp {med_txt}   a=snap shift, d=off",
            alignment_text(align_warp, SCALE),
        ])
    else:
        warp = np.zeros((DISP_H, DISP_W, 3), np.uint8)
        reason = "press d to enable" if matcher is not None else "CUDA StereoBM unavailable"
        draw_hud(warp, ["AFTER disparity warp — off", reason])

    cv2.imshow(WIN_BEFORE, before)
    cv2.imshow(WIN_AFTER, after)
    cv2.imshow(WIN_WARP, warp)

    key = cv2.waitKey(1) & 0xFF
    if key == ord('q'):
        break
    elif key in MODES:
        mode = MODES[key]
    elif key == ord('m'):
        show_mask = not show_mask
    elif key == ord('['):
        shift_disp -= 1
    elif key == ord(']'):
        shift_disp += 1
    elif key == ord('0'):
        shift_disp = 0
    elif key == ord('d'):
        show_warp = (not show_warp) and matcher is not None
        if not show_warp:
            med_disp_rect, align_warp = None, None
    elif key == ord('a') and med_disp_rect:
        # The single shift that best matches the dominant depth in view — what
        # the manual [/] shift converges to by hand
        shift_disp = int(round(med_disp_rect / SCALE))
    elif key == ord('c'):
        ts = int(time.time() * 1000)
        cv2.imwrite(os.path.join(CAPTURE_DIR, f"rectL_{ts}.png"), gpu_rectL.download())
        cv2.imwrite(os.path.join(CAPTURE_DIR, f"rectR_{ts}.png"), gpu_rectR.download())
        cv2.imwrite(os.path.join(CAPTURE_DIR, f"overlap_{mode}_before_{ts}.png"), before)
        cv2.imwrite(os.path.join(CAPTURE_DIR, f"overlap_{mode}_after_{ts}.png"), after)
        cv2.imwrite(os.path.join(CAPTURE_DIR, f"overlap_{mode}_warp_{ts}.png"), warp)
        print(f"[+] Captured overlap #{capture_count} → {CAPTURE_DIR}/")
        capture_count += 1

    frame_idx += 1

p0.terminate()
p1.terminate()
cv2.destroyAllWindows()

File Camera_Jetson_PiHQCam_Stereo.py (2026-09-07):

import sys
import os
sys.path.insert(0, os.path.abspath(os.path.join(os.path.dirname(__file__), "..")))

import time
import numpy as np
import cv2
from ISP.binning import extract_green
from camera_utils import initialize_camera_jetson, capture_raw_frame_jetson
from conversion_utils import bit16_to_bit8

# ─── Settings ──────────────────────────────────────────────────────────────────
LEFT_DEVICE  = "/dev/video0"
RIGHT_DEVICE = "/dev/video1"

W, H       = 3840, 2160
EXPOSURE   = 33000
GAIN       = 200
FRAME_RATE = 30000000

CALIB_FILE  = "Calibration_output/20260620_stereo_params.yml"
CAPTURE_DIR = "captures"

NUM_DISPARITIES  = 16 * 16  # must be multiple of 16; CUDA StereoBM max is 256; covers ~0.8 m to 5 m
BLOCK_SIZE       = 5       # must be odd; 5-21 for StereoBM
TEXTURE_THRESH   = 20       # mask pixels with too little texture (raise to kill more ghosts)
UNIQUENESS_RATIO = 20       # reject match if 2nd-best is within this % of best (0=off)
PREFILTER_CAP    = 31       # clamp prefilter response; 1-63
SPECKLE_WINDOW   = 0      # min area (px) to keep a disparity region; 0=off
SPECKLE_RANGE    = 32       # max disparity variation within a speckle region
DEPTH_MIN_M      = 0.3      # clip range for depth colormap (metres)
DEPTH_MAX_M      = 5.0
# ───────────────────────────────────────────────────────────────────────────────


def raw_to_gray8(raw_u16):
    """Raw 4K Bayer → 1920×1080 uint8 green channel (matches calibration resolution)."""
    return bit16_to_bit8(extract_green(raw_u16))


def load_calibration(path):
    fs = cv2.FileStorage(path, cv2.FILE_STORAGE_READ)
    map1x = fs.getNode("map1x").mat()
    map1y = fs.getNode("map1y").mat()
    map2x = fs.getNode("map2x").mat()
    map2y = fs.getNode("map2y").mat()
    Q     = fs.getNode("Q").mat()
    fs.release()
    focal    = Q[2, 3]           # focal length in pixels (from rectified projection)
    baseline = 1.0 / abs(Q[3, 2])  # baseline in metres
    return map1x, map1y, map2x, map2y, Q, focal, baseline


os.makedirs(CAPTURE_DIR, exist_ok=True)

print(f"[i] Loading calibration from '{CALIB_FILE}' ...")
map1x, map1y, map2x, map2y, Q, FOCAL_PX, BASELINE_M = load_calibration(CALIB_FILE)
print(f"[i] focal={FOCAL_PX:.1f} px  baseline={BASELINE_M*100:.1f} cm")

# Upload rectification maps to GPU once at startup
gpu_map1x = cv2.cuda_GpuMat(); gpu_map1x.upload(map1x)
gpu_map1y = cv2.cuda_GpuMat(); gpu_map1y.upload(map1y)
gpu_map2x = cv2.cuda_GpuMat(); gpu_map2x.upload(map2x)
gpu_map2y = cv2.cuda_GpuMat(); gpu_map2y.upload(map2y)

# CUDA StereoBM — faster than SGBM on GPU; WLS not compatible with CUDA matcher
matcher = cv2.cuda.createStereoBM(numDisparities=NUM_DISPARITIES, blockSize=BLOCK_SIZE)
matcher.setPreFilterType(cv2.StereoBM_PREFILTER_XSOBEL)  # edge filter reduces horizontal ghosting
matcher.setPreFilterCap(PREFILTER_CAP)
matcher.setTextureThreshold(TEXTURE_THRESH)
matcher.setUniquenessRatio(UNIQUENESS_RATIO)
# matcher.setSpeckleWindowSize(SPECKLE_WINDOW)
# matcher.setSpeckleRange(SPECKLE_RANGE)
stream = cv2.cuda.Stream()
print("[i] Using CUDA StereoBM (WLS disabled).")

print("[i] Initialising cameras ...")
pL, _ = initialize_camera_jetson(LEFT_DEVICE,  W, H, EXPOSURE, GAIN, FRAME_RATE)
pR, _ = initialize_camera_jetson(RIGHT_DEVICE, W, H, EXPOSURE, GAIN, FRAME_RATE)

print("[i] Running — press 'q' to quit, 'c' to capture.")

capture_count = 1

while True:
    raw_L = capture_raw_frame_jetson(pL, W, H)
    raw_R = capture_raw_frame_jetson(pR, W, H)
    if raw_L is None or raw_R is None:
        print("[!] Frame grab failed.")
        break

    grayL = raw_to_gray8(raw_L)
    grayR = raw_to_gray8(raw_R)

    # Upload to GPU and remap
    gpu_grayL = cv2.cuda_GpuMat(); gpu_grayL.upload(grayL)
    gpu_grayR = cv2.cuda_GpuMat(); gpu_grayR.upload(grayR)

    gpu_rectL = cv2.cuda.remap(gpu_grayL, gpu_map1x, gpu_map1y, cv2.INTER_LINEAR)
    gpu_rectR = cv2.cuda.remap(gpu_grayR, gpu_map2x, gpu_map2y, cv2.INTER_LINEAR)

    # Download rectified frames for capture
    rectL = gpu_rectL.download()
    rectR = gpu_rectR.download()

    # ── Rectified view — resize to 960×540 each on GPU → 1920×540 side-by-side
    bgrL = cv2.cuda.cvtColor(cv2.cuda.resize(gpu_rectL, (960, 540)), cv2.COLOR_GRAY2BGR).download()
    bgrR = cv2.cuda.cvtColor(cv2.cuda.resize(gpu_rectR, (960, 540)), cv2.COLOR_GRAY2BGR).download()
    both_bgr = cv2.rotate(np.hstack([bgrL, bgrR]), cv2.ROTATE_180)
    for y in range(0, both_bgr.shape[0], 30):
        cv2.line(both_bgr, (0, y), (both_bgr.shape[1] - 1, y), (0, 255, 0), 1)
    cv2.imshow("Rectified", both_bgr)

    # ── Disparity on GPU, download for post-processing ──────────────────────
    gpu_disp = matcher.compute(gpu_rectL, gpu_rectR, stream)
    disp = gpu_disp.download()

    # StereoBM returns 16x fixed-point; divide by 16 to get real pixel disparity
    disp_f   = disp.astype(np.float32)
    valid    = disp_f > 0.0

    # ── Disparity visualisation (raw disparity, uint8 clipped) ──────────────
    disp_vis = np.zeros(disp_f.shape, dtype=np.uint8)
    disp_vis[valid] = np.clip(disp_f[valid], 0, 255)
    disp_display = cv2.rotate(cv2.resize(cv2.applyColorMap(disp_vis, cv2.COLORMAP_TURBO), (960, 540)), cv2.ROTATE_180)
    cv2.imshow("Disparity", disp_display)

    # ── Depth map: depth = focal * baseline / disparity ─────────────────────
    depth_m = np.zeros(disp_f.shape, dtype=np.float32)
    depth_m[valid] = (FOCAL_PX * BASELINE_M) / disp_f[valid]
    depth_clipped = np.clip(depth_m, DEPTH_MIN_M, DEPTH_MAX_M)
    # Map DEPTH_MAX_M → 0 (blue/far) and DEPTH_MIN_M → 255 (red/near)
    depth_norm = ((DEPTH_MAX_M - depth_clipped) / (DEPTH_MAX_M - DEPTH_MIN_M) * 255).astype(np.uint8)
    depth_norm[~valid] = 0
    depth_display = cv2.rotate(cv2.resize(cv2.applyColorMap(depth_norm, cv2.COLORMAP_TURBO), (960, 540)), cv2.ROTATE_180)
    cv2.imshow("Depth (m)", depth_display)

    key = cv2.waitKey(1) & 0xFF
    if key == ord('q'):
        break
    elif key == ord('c'):
        ts = int(time.time() * 1000)
        cv2.imwrite(os.path.join(CAPTURE_DIR, f"rectL_{ts}.png"), rectL)
        cv2.imwrite(os.path.join(CAPTURE_DIR, f"rectR_{ts}.png"), rectR)
        cv2.imwrite(os.path.join(CAPTURE_DIR, f"depth_{ts}.png"), disp_vis)
        print(f"[+] Captured pair #{capture_count} → captures/")
        capture_count += 1

pL.terminate()
pR.terminate()
cv2.destroyAllWindows()

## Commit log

2025-07-10 Update CameraISP_RapsberryPI_HQcam.py
    Added black light subtraction algo. Histogram will be displayed before and after the subtraction in real time.
2025-07-10 Update CameraISP_RapsberryPI_HQcam.py
    Perform black offset calibration using optically black regions on the sensor.
2025-07-14 add CAD files for the case, PI5, camera etc
    Add resources downloaded elsewhere
    [CIL034-F2.7-M12A660 v3.stp, CIL034-F2.7-M12ANIR v3.stp, CLA-M12-C-Adapter.stp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]
2025-07-15 add BlackOffsetMeasurement and VignettingMeasurement. Measured Lens shading, saved to flat_field_average.npy
2025-07-16 Add lens shading correction
    [Camera_ISP_RapsberryPI_HQcam.py]
2025-07-17 completed white balance calibration using 50% grey patch, added gray world and white patch algo.
2025-07-17 Adding Script for Color Calibration
2025-07-21 ongoing color calibration andfolder and module reorganization
2025-07-22 update wb to use the correct patch
    [Camera_ISP_RapsberryPI_HQcam.py, color_calibration.py, conversion_utils.py]
2025-07-23 add functional color calibration
2025-07-24 Add saturation clamping and realtime awb, ccm
2025-08-04 Changing to use 16 bit Pi HQ Camera output, modified black offset and stribing function
2025-09-03 add hello stereo camera
2025-09-04 stereo calibration script
2025-09-05 update stereo calibration script
2025-09-07 add stereo camera calibrated file, hello depth map
2026-02-05 Test GPU OpenCV from jetson
2026-02-05 set up env on orion nano
    [pyvenv.cfg]
2026-02-09 Trying to grab raw bayer images from Pi HQ Camera using Jetson Orion Nano
2026-03-09 sucessfully read raw image from Pi HQ camera using Jetson Orion Nano
2026-06-13 Sucessful implmentation of PiHQ Camera using Jetson Orion Nano
2026-06-15 added calibration script and show the first depth map using Jeton Nano
2026-06-15 add WLS filter for better depth map
2026-06-17 Add script for stereo calibration validation
2026-06-20 Used cuda for Stereo Camera depth map generation for speed up
2026-06-21 Added new stereo calibration method to capture images first, then calibrate. This allows calibration with 1920x1080 high resolution.
2026-09-07 Add stereo camera calibration validation script
    Claude-Session: https://claude.ai/code/session_01J5XvPGKYavax8cXURGbxFp
2026-09-07 add charuco chart design script and printout pdf
    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
2026-10-24 Increased frameRate to 5fps and archived some old scripts
